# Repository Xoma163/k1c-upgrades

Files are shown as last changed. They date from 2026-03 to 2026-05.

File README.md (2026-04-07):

# k1c-upgrades

Klipper configs, mods, and upgrade notes for the Creality K1C.

## О репозитории

Этот репозиторий — моя личная база для хранения:

- конфигов принтера Creality K1C;
- заметок по модификациям;
- полезных ссылок;
- нюансов установки и использования.

Здесь нет подробных пошаговых инструкций — только краткие заметки и выжимка по тому, что оказалось полезным на практике.

## Что используется

- [SimpleAF + Eddy NG](https://pellcorp.github.io/creality-wiki/eddyng/) с **Default** креплением
- [Purcell nozzle wipe](https://pellcorp.github.io/creality-wiki/nozzle_wipe/#purcell-nozzle-wipe) с **V5K1C** креплением 

## Структура репозитория

- [`config/default`](config/default) — reference-база
- [`config/k1c #1`](config/k1c%20%231) — рабочие конфиги первого принтера
- [`config/k1c #2`](config/k1c%20%232) — рабочие конфиги второго принтера

Все мои ручные изменения в конфигах отмечены комментарием: `# custom andrewsha`

## Документация

- [Прошивка и конфиги](docs/firmware-and-configs.md)
- [Рабочая область и мёртвые зоны стола](docs/bed-area-and-dead-zones.md)
- [Модификации, детали и расходники](docs/mods-and-parts.md)
- [Полезные ссылки](docs/links.md)
- [TODO](docs/todo.md)

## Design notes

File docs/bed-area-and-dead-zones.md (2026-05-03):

# Рабочая область и мёртвые зоны стола

Для моего K1C есть несколько зон, которые надо исключать и в слайсере, и при настройке bed mesh.

## Исходные вводные

- заявленная область печати: `220x220`;
- фактический ход головы больше: примерно `226x229`;
- `0,0` — левый нижний угол стола;
- хоуминг происходит в правом нижнем углу.

## Какие зоны считаю unsafe

1. Левая мёртвая полоса (крепление Eddy):
   - если `x < 5`, печатать нельзя

2. Нижний левый угол (кастомные петли двери):
   - прямоугольник `0..8 x 0..5`

3. Верхняя полоса стола (датчик окончания филамента, провода, радиатор мотора экструдера):
   - из-за реального хода головы сверху запрещаю всё, что `y >= 210`
   - для рабочей области `220x220` это даёт прямоугольник: `0..220 x 210..220`

4. Зона щётки:
   - `165,225`
   - `165,205`
   - `85,205`
   - `85,225`
   - это даёт прямоугольник: `85..165 x 205..225`

## OrcaSlicer

### Print area
Лучше использовать не список исключённых областей, а готовый SVG: [orca-print-area.svg](orca-print-area.svg)

### Exclude area
В OrcaSlicer `multiple exclusion areas` нормально не поддерживаются, поэтому использую один связный полигон для `Excluded area`:

```text
0x0,8x0,8x5,5x5,5x210,85x210,85x205,165x205,165x210,220x210,220x220,0x220
```

Этот полигон исключает:

- полосу `x < 5`;
- нижний левый угол `0..8 x 0..5` из-за кастомных петель двери;
- верхнюю полосу `y >= 210`;
- зону щётки `85..165 x 205..225`.

## Klipper bed_mesh

Для `bed_mesh` оставляю 3 простых ограничения по рабочей области:

- `x > 5`;
- внизу слева дополнительно исключаю прямоугольник `0..8 x 0..5`;
- `y < 205`.

Через `faulty_region` это задаётся так:

```ini
# Left dead zone: avoid probing if X is below 5 mm
faulty_region_1_min: 0,0
faulty_region_1_max: 5,204.999
# Door hinges: avoid probing in the lower-left 0..8 x 0..5 rectangle
# Start slightly to the right of X=5 to avoid region overlap
faulty_region_2_min: 5.001,0
faulty_region_2_max: 8,5
# Top dead zone: avoid probing in the whole top strip above Y=205
faulty_region_3_min: 0,205
faulty_region_3_max: 220,220
```

### Где это лежит в конфиге сейчас

Текущая реализация в рабочих конфигах вынесена в override-слой:

- `faulty_region_*` живут в `custom.cfg` внутри секции `[bed_mesh]`;
- fixed purge / fixed smart park живут в `custom_macros.cfg` через `_SAF_LINE_PURGE` и `_SAF_SMART_PARK`;
- сами fixed координаты хранятся в `_CUSTOM_ANDREWSHA_SETTINGS` внутри `custom.cfg`.

Для обоих рабочих наборов сейчас используются такие fixed координаты purge/park:

- старт purge / park: `X=85`, `Y=212`;
- конец purge: `X=35`, `Y=212`;
- после purge есть дополнительный безопасный уход в `X35 Y200`.

## Тестовый G-code для проверки границы

Ниже тестовый G-code, который медленно проходит по боевой границе доступной области без экструзии:

```gcode
G90
G28
G1 Z10 F600
G1 X8 Y0 F1800
G1 X220 Y0 F1200
G1 X220 Y210 F1200
G1 X165 Y210 F1200
G1 X165 Y205 F1200
G1 X85 Y205 F1200
G1 X85 Y210 F1200
G1 X5 Y210 F1200
G1 X5 Y5 F1200
G1 X8 Y5 F1200
G1 X8 Y0 F1200
```

### Важно

- запускать этот тест лучше с рукой на **Emergency Stop**;
- безопаснее всего запускать его **построчно из консоли Klipper/Mainsail/Fluidd**, а не целым файлом;
- перед запуском убедитесь, что сопло поднято, стол пустой, а рядом нет клипс, инструментов и посторонних деталей.

## Тестовая STL-рамка по боевой границе

В репозитории лежит готовая модель: [`dead-zone-boundary-frame.stl`](dead-zone-boundary-frame.stl)

Что это такое:

- тонкая рамка по боевой границе доступной области;
- сама рамка построена не по точной боевой границе, а по контрольному контуру, вжатому внутрь примерно на `1 мм` с каждой стороны;
- высота модели `0.2 мм`;
- ширина линии рамки примерно `1 мм`.

Смысл модели — быстро проверить реальную печать по границе разрешённой зоны с учётом:

- слева в основном поле `x >= 6`;
- внизу слева контрольного выреза под петли двери `0..9 x 0..6`;
- `y < 209`;
- дополнительно расширенного контрольного выреза под щётку `83..167 x 203..226`.

Перед реальной печатью этой STL всё равно лучше сначала прогнать тестовый G-code выше, а саму первую печать запускать под наблюдением.

### Как печатать эту STL в OrcaSlicer

1. Временно включить ограничения стола и свериться, что модель встаёт правильно относительно мёртвых зон.
2. Разместить модель в позиции `X=112.50`, `Y=105.0`.
3. Проверить визуально, что рамка проходит там, где ожидается.
4. Временно убрать ограничения стола.
5. Отправить модель на печать.
6. Если печать прошла нормально, вернуть ограничения стола обратно.

Это нужно потому, что OrcaSlicer считает модель слишком близкой к области исключения и не даёт запустить печать, даже если эта тестовая рамка специально сделана для проверки самой границы.

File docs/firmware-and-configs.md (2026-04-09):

# Прошивка и конфиги

## Что используется

- [SimpleAF + Eddy NG](https://pellcorp.github.io/creality-wiki/eddyng/) с **Default** креплением;
- [Purcell nozzle wipe](https://pellcorp.github.io/creality-wiki/nozzle_wipe/#purcell-nozzle-wipe) с креплением **V5K1C**.

## Почему SimpleAF

Я сознательно ушёл от стоковой прошивки `Creality` и `Creality Helper Script` в пользу конфигурации, где можно полностью контролировать:

- хоуминг;
- bed mesh;
- старт/завершение печати;
- purge / park / wipe сценарии;
- fan logic и обслуживающие макросы.

## Важное ограничение

Если планируете переход на SimpleAF, нужен альтернативный способ картографии стола.

В этой конфигурации используется **BTT Eddy / Eddy NG**, потому что SimpleAF **не опирается на штатные тензодатчики K1C** как на основной механизм картографии.

## Где лежат конфиги

Все конфиги находятся в [`config`](../config).

Структура такая:

- [`config/default`](../config/default) — reference-база, ближайшая к апстриму SimpleAF;
- [`config/k1c #1`](../config/k1c%20%231) — рабочий набор первого принтера;
- [`config/k1c #2`](../config/k1c%20%232) — рабочий набор второго принтера.

Важно: `k1c #1` и `k1c #2` — это **самодостаточные рабочие наборы**, а не наследование от `default/` на runtime.

## Ключевые файлы

### Базовые

- `printer.cfg` — главный входной файл Klipper, include-порядок и hardware-секции;
- `homing.cfg` — sensorless XY, `homing_override`, проверки перед Z homing;
- `eddyng.cfg` — probe, mesh, screws tilt, axis twist;
- `eddyng_macro.cfg` — обёртки вокруг `BED_MESH_CALIBRATE` и `PROBE_EDDY_NG_TAP`;
- `start_end.cfg` — `START_PRINT`, `END_PRINT`, pause/resume/cancel/runout;
- `fan_control.cfg` — логика part/chamber/auxiliary/hotend fan;
- `useful_macros.cfg` — сервисные макросы, включая загрузку/выгрузку филамента.

### Кастомные

- `custom.cfg` — значения и overrides, которые должны идти поверх дефолтных секций;
- `custom_macros.cfg` — поведенческие overrides через `_SAF_*` hooks;
- `advanced_nozzle_cleaner.cfg` — отдельный модуль Purcell nozzle wipe.

### Moonraker / UI

- `moonraker.conf` — Moonraker и include'ы;
- `webcam.conf` — локальный URL камеры;
- `grumpyscreen.ini` — настройки экрана.

## Текущая стратегия кастомизации

Текущая цель репозитория — держать рабочие конфиги как можно ближе к `default/`, а ручные правки концентрировать в явных override-слоях.

Подробно схема описана в отдельном файле: [Слои кастомизации и override-стратегия](config-overrides.md).

Короткая версия:

- `printer.cfg` остаётся максимально близким к дефолту;
- `custom.cfg` хранит численные и variable-based overrides;
- `custom_macros.cfg` хранит поведенческие overrides через `_SAF_*` hooks;
- большие отдельные модули остаются отдельными include-файлами.

## Как помечаются ручные правки

Ручные изменения стараюсь отмечать комментарием `# custom andrewsha`.

Но с текущей архитектурой сама по себе локация правки уже тоже несёт смысл:

- если изменение лежит в `custom.cfg`, это override значения;
- если лежит в `custom_macros.cfg`, это override поведения;
- если лежит в `advanced_nozzle_cleaner.cfg`, это отдельный модуль nozzle wipe.

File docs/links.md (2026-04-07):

# Полезные ссылки

## Основные источники

- [SimpleAF docs](https://pellcorp.github.io/creality-wiki/)
- [SimpleAF + Eddy NG](https://pellcorp.github.io/creality-wiki/eddyng/)
- [Purcell nozzle wipe](https://pellcorp.github.io/creality-wiki/nozzle_wipe/#purcell-nozzle-wipe)
- [Основная таблица с апгрейдами](https://docs.google.com/spreadsheets/d/1lo7YX4nkfYGhhncVtIryOvbDM4tTaRjzZT0Y3F5O7gI)

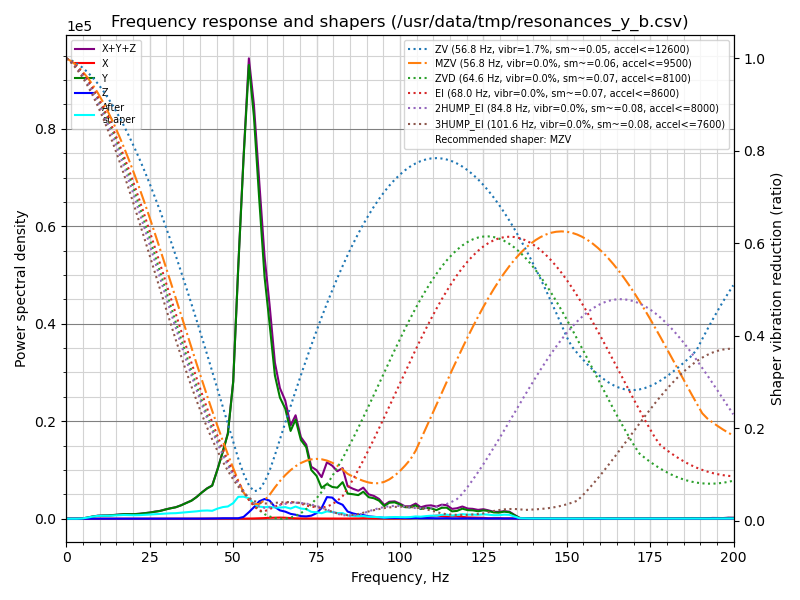
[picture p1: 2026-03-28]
config/k1c #1/images/resonances_y.png

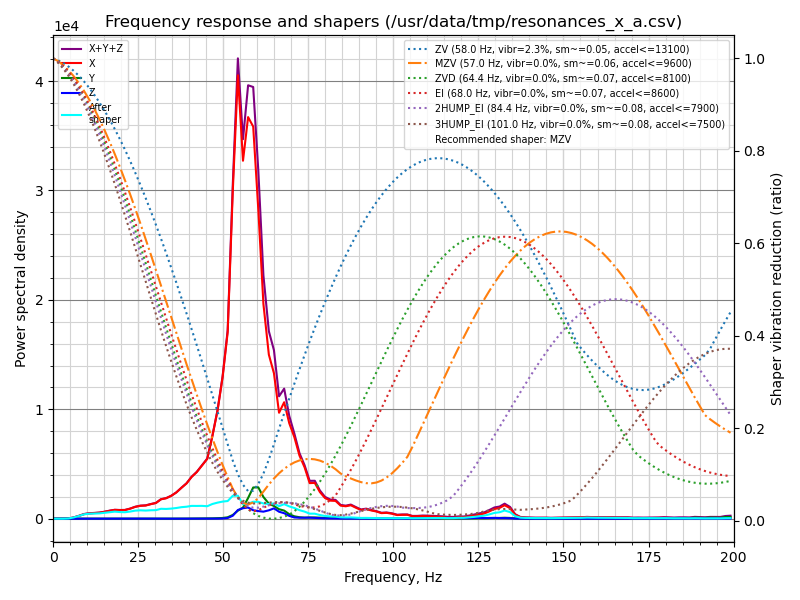
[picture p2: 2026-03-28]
config/k1c #2/images/resonances_x.png

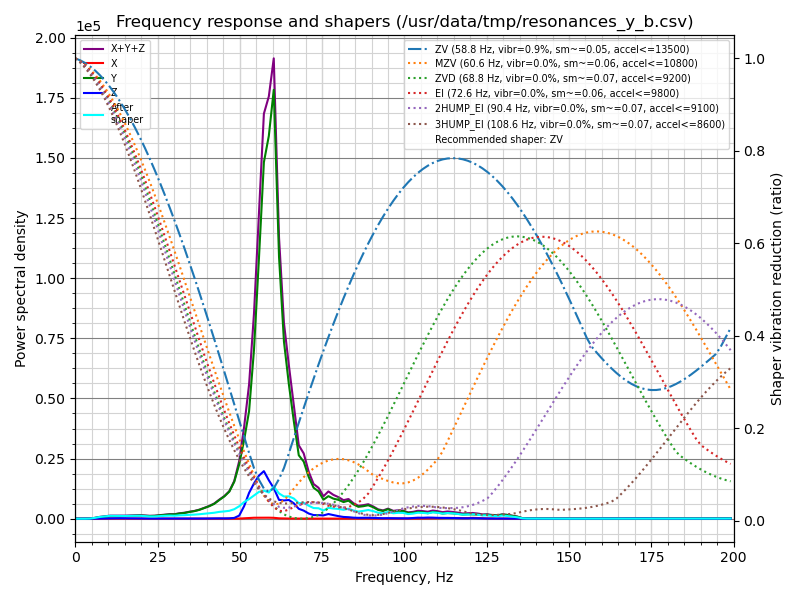
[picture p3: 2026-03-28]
config/k1c #2/images/resonances_y.png

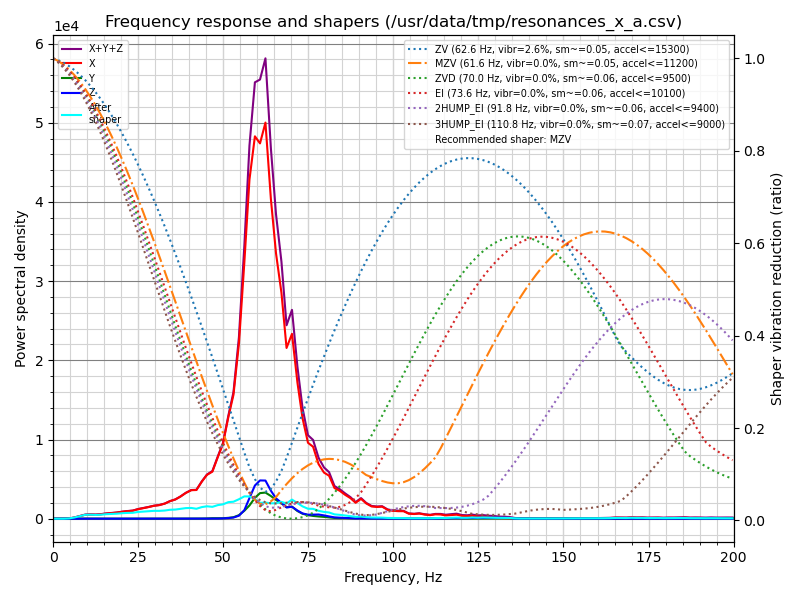
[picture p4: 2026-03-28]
config/k1c #1/images/resonances_x.png

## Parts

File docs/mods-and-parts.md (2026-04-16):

# Модификации, детали и расходники

## Печатные модификации

- [Райзер](https://www.printables.com/model/951012-creality-k1-k1c-k1se-lid-riser-v3-frame-extension)
- [Держатель щётки](https://www.printables.com/model/1023575-prowiper-for-creality-k1-series)
    - V5K1C крепление: `V5 K1C BRUSH MOUNT FOR A1 BRUSHES.stl`
- [Петли для дверцы](https://www.printables.com/model/916563-creality-k1-k1c-door-hinges-geared-print-in-place)
- [Фильтр HEPA для выдувного кулера](https://www.printables.com/model/1618123-hepa-filter-case-for-creality-k1c)
- [Полочка под принтер](https://www.printables.com/model/1114893-k1c-empty-tray)
- [Крепление BTT Eddy](https://www.printables.com/model/1637215-remix-of-btteddy-creality-k1-k1c-k1-max-mount-to-w)
- [Кабельная цепь](https://www.printables.com/model/1684322-cable-chain-for-k1k1c-with-ptfe-guide-increased-fo)

- [Держатель трубки филамента для сушилки](https://www.printables.com/model/1022857-creality-space-pi-pfte-holder)

## Покупные модификации

- Eddy
    - [Картограф BIGTREETECH Eddy Duo Eddy](https://aliexpress.ru/item/1005006917842625.html)
    - [Коннекторы JST PH 2.0мм 4pin (для подключения Eddy)](https://www.ozon.ru/product/jst-ph-2-0mm-4pin-kabel-s-razemom-30sm-razem-na-platu-jst-ph-4pin-5sht-1854551013/)
    - [Коннекторы JST PH 1.5мм 4pin (для подключения Eddy)](https://www.ozon.ru/product/jst-zh-1-5-mm-4pin-kabel-s-razemom-30sm-razem-na-platu-jst-zh-4pin-5sht-2624681705/)
    - [Кабель силиконовый 4pin 0.12мм^2 (для подключения Eddy)](https://www.ozon.ru/product/microtec-silovoy-kabel-4-x-0-12-mm-3-m-1867569044/)

- Моторы и радиаторы
    - [Радиаторы моторов XYZ](https://aliexpress.ru/item/32624104352.html)
    - [Радиатор мотора экструдера](https://aliexpress.ru/item/1005008673674752.html)

- Остальное
    - [Бипер](https://aliexpress.ru/item/1005006744589368.html)
    - [Экструдер FYSETC Phaetus DXC V1.1](https://aliexpress.ru/item/1005009096708545.html)
    - [Прозрачная PTFE трубка 2.5 x 4 мм](https://aliexpress.ru/item/1005007856169379.html)
    - [Кабель канал 25 x 16мм](https://www.ozon.ru/product/kabel-kanal-ruvinil-25h16-mm-chernyy-1-metr-1-sht-502978136/)
    - [Винты M3](https://www.ozon.ru/product/vint-m-3h16-s-potaynoy-golovkoy-din-965-100-sht-874104112/)
    - [Латунные втулки M3](https://www.ozon.ru/product/120-sht-m3x5-7-od4-6-rezba-s-nakatkoy-iz-latuni-s-rezboy-termostoykaya-termostoykaya-vstavka-1719174667/)

## Расходники

- [Оригинальные печатные пластины](https://aliexpress.ru/item/1005006912703598.html)
- [Неоригинальные печатные пластины](https://aliexpress.ru/item/1005006604536598.html)
- [Носки](https://aliexpress.ru/item/1005007193585076.html)
- [Щётки](https://aliexpress.ru/item/1005007695468858.html)
- [Сопла Trianglelab unicorn](https://aliexpress.ru/item/1005006727982293.html)
- [Сопла Creality unicorn](https://aliexpress.ru/item/1005006861530583.html)
- [Железные шестерни экструдера](https://aliexpress.ru/item/1005007150902009.html)
- [Стоковый хотенд в сборе](https://aliexpress.ru/item/1005008125402700.html)
- [Клей для 3д печати](https://www.ozon.ru/product/kley-dlya-3d-fdm-pechati-250-ml-universalnyy-dlya-3d-printera-kley-dlya-vseh-vidov-plastika-788061034)

## Полезные штучки

- [Сушилка филамента Creality Space Pi Fillament Dryer Plus](https://aliexpress.ru/item/1005006458650443.html)

## Откуда брать идеи для модов?

- [Основная таблица с апгрейдами](https://docs.google.com/spreadsheets/d/1lo7YX4nkfYGhhncVtIryOvbDM4tTaRjzZT0Y3F5O7gI)

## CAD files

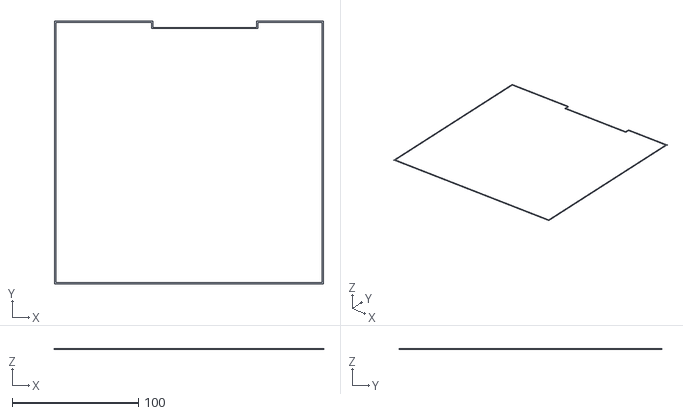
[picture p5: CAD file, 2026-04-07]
docs/dead-zone-boundary-frame.stl
213.0 x 208.0 x 0.2

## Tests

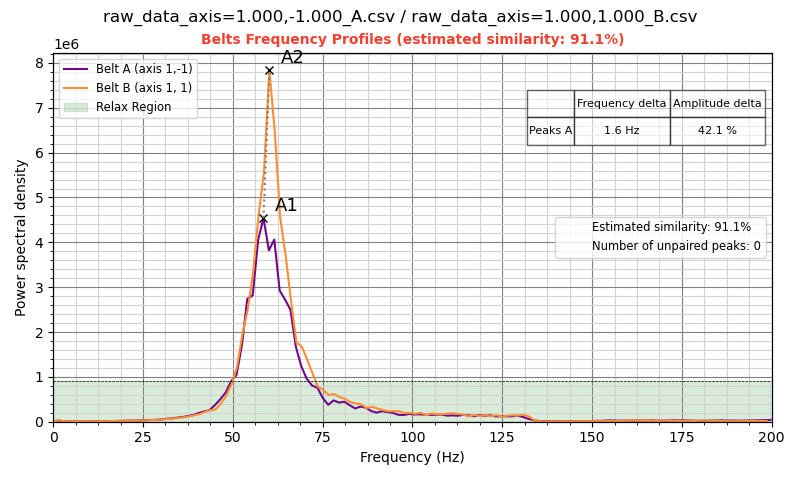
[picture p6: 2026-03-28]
config/k1c #2/images/belts_calibration.png

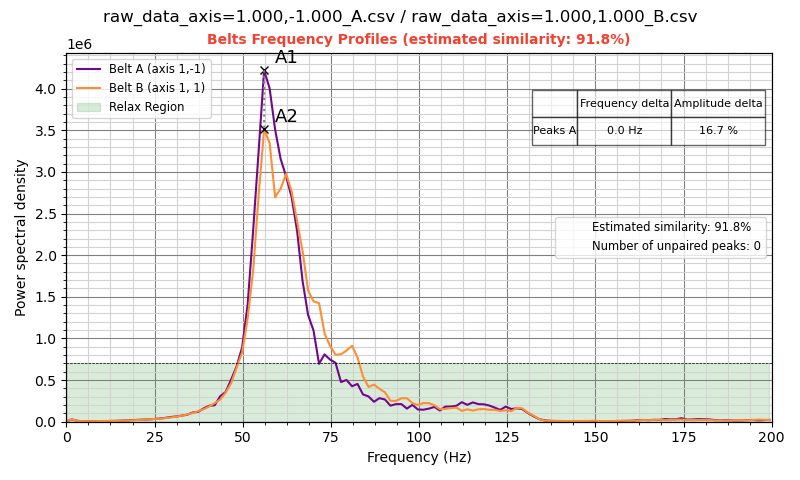
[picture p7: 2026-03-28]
config/k1c #1/images/belts_calibration.png

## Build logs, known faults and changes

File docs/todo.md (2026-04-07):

# TODO

- Заменить `variable_purge_start_y` и `variable_purge_end_y` с `212` на `215`, когда заменю пластины

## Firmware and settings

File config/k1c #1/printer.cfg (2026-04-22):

# Modified by Simple AF 2026-03-28_13-22-50

[include homing.cfg]

[include internal_macros.cfg]

[include useful_macros.cfg]

[include belts_calibration.cfg]

[include start_end.cfg]

[include Line_Purge.cfg]

[include Smart_Park.cfg]

[include fan_control.cfg]

[include client.cfg]

[include quickstart.cfg]

[include eddyng.cfg]

[include eddyng_macro.cfg]

[mcu]
serial: /dev/ttyS7
baud: 230400
restart_method: command

[mcu nozzle_mcu]
serial: /dev/ttyS1
baud: 230400
restart_method: command

[verify_heater extruder]
[verify_heater heater_bed]
check_gain_time: 120
heating_gain: 1.0
hysteresis: 10

[gcode_arcs]
resolution: 1.0

[stepper_x]
step_pin: PC2
dir_pin: !PB9
enable_pin: !PC3
microsteps: 32
rotation_distance: 40
endstop_pin: tmc2209_stepper_x:virtual_endstop
position_endstop: 229
position_min: -5
position_max: 229
homing_speed: 30
homing_retract_dist:0

[tmc2209 stepper_x]
uart_pin:PA9
interpolate: True
run_current:1.5
sense_resistor: 0.100
stealthchop_threshold: 0
uart_address:3
diag_pin: ^PB12
# driver_IHOLDDELAY: 8
# driver_TPOWERDOWN: 20
# driver_TBL: 1
# driver_TOFF: 1
# driver_HEND: 0
# driver_HSTRT: 7
driver_SGTHRS: 75
# hold_current:1.0

[stepper_y]
step_pin: PB8
dir_pin: !PB7
enable_pin: !PC3
microsteps: 32
rotation_distance: 40
endstop_pin: tmc2209_stepper_y:virtual_endstop
position_endstop: -0.5
position_min: -0.5
position_max: 226
homing_speed: 30
homing_retract_dist:0

[tmc2209 stepper_y]
uart_pin:PA10
interpolate: True
run_current:1.5
sense_resistor: 0.100
stealthchop_threshold: 0
uart_address:3
diag_pin: ^PB13
# driver_IHOLDDELAY: 8
# driver_TPOWERDOWN: 20
# driver_TBL: 1
# driver_TOFF: 1
# driver_HEND: 0
# driver_HSTRT: 7
driver_SGTHRS: 75
# hold_current:1.0

[stepper_z]
step_pin: PB6
dir_pin: !PB5
enable_pin: !PC3
microsteps: 16
rotation_distance:8
gear_ratio: 64:20
endstop_pin: probe:z_virtual_endstop
position_max: 252
position_min: -5
# position_endstop: 0

[tmc2209 stepper_z]
uart_pin: PA11
uart_address: 3
run_current: 0.8
diag_pin: ^PB14
stealthchop_threshold: 0
sense_resistor: 0.100
# driver_IHOLDDELAY: 8
# driver_TPOWERDOWN: 20
# driver_TBL: 1
# driver_TOFF: 1
# driver_HEND: 2
# driver_HSTRT: 2
driver_SGTHRS: 0

[extruder]
max_extrude_only_distance: 1000.0
max_extrude_cross_section: 80
step_pin: nozzle_mcu:PB1
dir_pin: nozzle_mcu:PB0
enable_pin: !nozzle_mcu:PB2
microsteps: 16
rotation_distance: 6.9
nozzle_diameter: 0.400
filament_diameter: 1.750
heater_pin: nozzle_mcu:PB7
sensor_type: EPCOS 100K B57560G104F
sensor_pin: nozzle_mcu:PA0
pressure_advance: 0.04
pressure_advance_smooth_time: 0.040
control: pid
pid_Kp: 25.013
pid_Ki: 2.566
pid_Kd: 60.966
min_temp: 0
max_temp: 320

[tmc2209 extruder]
uart_pin: nozzle_mcu:PB11
tx_pin: nozzle_mcu:PB10

uart_address: 3
run_current: 0.55
sense_resistor: 0.150
stealthchop_threshold: 0
# driver_IHOLDDELAY: 8
# driver_TPOWERDOWN: 20
# driver_TBL: 2
# driver_TOFF: 3
# driver_HEND: 0
# driver_HSTRT: 5

[heater_bed]
heater_pin: PB10
sensor_type: EPCOS 100K B57560G104F
sensor_pin: PC4
control: watermark
min_temp: 0
max_temp: 115

[filament_switch_sensor filament_sensor]
pause_on_runout: false
switch_pin: !PC15
runout_gcode: _ON_FILAMENT_RUNOUT

[output_pin LED]
pin:PB0
pwm: True
cycle_time: 0.010
value: 1

[adxl345]
cs_pin: nozzle_mcu:PA4
spi_speed: 5000000
axes_map: x,-z,y
spi_software_sclk_pin: nozzle_mcu:PA5
spi_software_mosi_pin: nozzle_mcu:PA7
spi_software_miso_pin: nozzle_mcu:PA6

[resonance_tester]
accel_chip: adxl345
accel_per_hz: 75
# min_freq: 30
# max_freq: 100
probe_points:
   110,110,10

[printer]
kinematics: corexy
max_velocity: 600
max_accel: 20000
max_z_velocity: 10
square_corner_velocity: 5.0
# square_corner_max_velocity: 200.0
# max_accel_to_decel: 20000
max_z_accel: 300

[probe_eddy_ng btt_eddy]

[exclude_object]

# custom andrewsha https://pellcorp.github.io/creality-wiki/nozzle_wipe/#purcell-nozzle-wipe
[include advanced_nozzle_cleaner.cfg]

# custom andrewsha (переопределения переменных)
[include custom.cfg]

# custom andrewsha (переопределения макросов)
[include custom_macros.cfg]

#*# <---------------------- SAVE_CONFIG ---------------------->
#*# DO NOT EDIT THIS BLOCK OR BELOW. The contents are auto-generated.
#*#
#*# [bed_mesh default]
#*# version = 1
#*# points =
#*# 	-0.007990, 0.001714, -0.023951, -0.043306, -0.058533, -0.059196, -0.042648, -0.028529, -0.027213, -0.021002, -0.018720, -0.037382, -0.051236, -0.049915, -0.047927, -0.045949, -0.035748, -0.045949, -0.044957, -0.051236
#*# 	0.015546, 0.020992, -0.008639, -0.019372, -0.038039, -0.036724, -0.014819, -0.001200, 0.000426, 0.004296, 0.002683, -0.011891, -0.033437, -0.033437, -0.033437, -0.019382, -0.027538, -0.034751, -0.046608, -0.059196
#*# 	0.001072, 0.011377, -0.001838, -0.007342, -0.025577, -0.021002, -0.003454, 0.008807, 0.015870, 0.017798, 0.011059, -0.008639, -0.024923, -0.028193, -0.024269, -0.015471, -0.025577, -0.034751, -0.050575, -0.066850
#*# 	-0.016440, 0.001072, 0.002989, 0.012021, -0.017743, -0.015138, -0.000870, 0.009452, 0.011377, 0.008807, 0.009760, -0.004107, -0.029503, -0.033459, -0.039352, -0.034751, -0.041989, -0.047927, -0.058533, -0.075877
#*# 	-0.033437, -0.003454, 0.002038, 0.009452, -0.005722, -0.005399, 0.007516, 0.010097, 0.005588, -0.002487, -0.009290, -0.011571, -0.036724, -0.038054, -0.050575, -0.042663, -0.056536, -0.060859, -0.069183, -0.075537
#*# 	-0.042003, -0.013838, -0.001838, 0.008162, -0.004103, -0.007342, -0.004102, -0.000870, -0.002499, -0.022308, -0.030159, -0.039684, -0.049255, -0.052893, -0.056536, -0.055212, -0.050590, -0.065519, -0.069183, -0.080569
#*# 	-0.055874, -0.017743, -0.000870, 0.018104, 0.008794, -0.003454, 0.002674, -0.007342, -0.017743, -0.028848, -0.032782, -0.039027, -0.046608, -0.045949, -0.047267, -0.047927, -0.054550, -0.059859, -0.066523, -0.076545
#*# 	-0.060522, -0.024923, -0.014814, 0.001072, 0.001718, -0.005399, -0.010585, -0.006381, -0.024923, -0.030814, -0.033437, -0.034751, -0.031811, -0.034751, -0.036724, -0.034751, -0.041330, -0.046608, -0.050575, -0.066523
#*# 	-0.068523, -0.036395, -0.024269, -0.000870, 0.007198, 0.000426, -0.007990, -0.013187, -0.010923, -0.011892, -0.009623, -0.016440, -0.014814, -0.016440, -0.019697, -0.024596, -0.019703, -0.027876, -0.024269, -0.049915
#*# 	-0.094037, -0.058533, -0.019697, -0.013511, -0.013200, -0.002495, -0.019372, -0.023942, -0.033437, -0.021993, -0.024923, -0.022962, -0.024269, -0.023616, -0.024269, -0.024269, -0.023299, -0.038039, -0.041989, -0.059196
#*# 	-0.107591, -0.058197, -0.034751, -0.014162, -0.010263, -0.015789, -0.025577, -0.034751, -0.042648, -0.044629, -0.036395, -0.029843, -0.040673, -0.041330, -0.044629, -0.043306, -0.056536, -0.053563, -0.058206, -0.081909
#*# 	-0.052904, -0.024923, -0.007342, 0.003649, -0.004103, -0.009940, -0.021002, -0.033437, -0.048921, -0.051236, -0.043306, -0.044957, -0.049255, -0.049915, -0.050575, -0.052893, -0.061185, -0.061533, -0.077214, -0.099444
#*# 	-0.046608, 0.003649, 0.017155, 0.020357, 0.005906, -0.008639, -0.011241, -0.032782, -0.047267, -0.044307, -0.041346, -0.049915, -0.053889, -0.057534, -0.063851, -0.070189, -0.072878, -0.082929, -0.094037, -0.109971
#*# 	-0.032800, -0.005399, 0.003649, 0.003649, -0.007342, -0.021655, -0.025577, -0.034751, -0.047927, -0.036724, -0.045948, -0.047267, -0.052893, -0.055212, -0.059196, -0.064515, -0.075209, -0.088299, -0.096055, -0.119192
#*# 	-0.027876, 0.015546, 0.008162, 0.001072, -0.012542, -0.032782, -0.031811, -0.041330, -0.042006, -0.047267, -0.042648, -0.047267, -0.038696, -0.059196, -0.058549, -0.066194, -0.089315, -0.095383, -0.102164, -0.117127
#*# 	-0.041000, -0.009290, -0.013187, -0.019372, -0.034751, -0.051236, -0.053889, -0.042003, -0.042003, -0.047267, -0.041989, -0.039697, -0.051236, -0.048933, -0.063187, -0.069183, -0.080569, -0.094037, -0.101489, -0.114751
#*# 	-0.051236, -0.015789, -0.019697, -0.025577, -0.029503, -0.056536, -0.055212, -0.053889, -0.051896, -0.048261, -0.039697, -0.038696, -0.062187, -0.051896, -0.072529, -0.072536, -0.092346, -0.102838, -0.110999, -0.122948
#*# 	-0.064515, -0.042648, -0.041330, -0.036739, -0.043650, -0.055212, -0.052893, -0.051236, -0.049255, -0.047267, -0.044957, -0.051896, -0.053567, -0.063851, -0.063187, -0.056885, -0.072527, -0.085272, -0.094710, -0.116448
#*# 	-0.053889, -0.038039, -0.043964, -0.044957, -0.047927, -0.047927, -0.042648, -0.041330, -0.041989, -0.042648, -0.042648, -0.055212, -0.065180, -0.063851, -0.058533, -0.057870, -0.067854, -0.075877, -0.081909, -0.091015
#*# 	-0.085272, -0.071862, -0.073860, -0.068868, -0.079901, -0.065531, -0.067188, -0.064515, -0.064515, -0.066523, -0.066523, -0.070196, -0.086612, -0.082578, -0.070191, -0.065519, -0.072529, -0.077214, -0.081239, -0.094725
#*# x_count = 20
#*# y_count = 20
#*# mesh_x_pps = 2
#*# mesh_y_pps = 2
#*# algo = bicubic
#*# tension = 0.2
#*# min_x = 10.0
#*# max_x = 204.94
#*# min_y = 10.0
#*# max_y = 209.88000000000005
#*#
#*# [bed_mesh default_cold_20x20]
#*# version = 1
#*# points =
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

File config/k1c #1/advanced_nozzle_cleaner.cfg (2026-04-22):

# https://pellcorp.github.io/creality-wiki/nozzle_wipe/#purcell-nozzle-wipe

# CHANGE THE BRUSH MOUNT VERSION BELOW. THE REST WILL AUTO DETECT WHEN RUNNING THE MACRO
# SET PRINTER VERSION TO CUSTOM TO OVERRIDE AUTOCONFIG. YOU MUST MANUALLY SET ALL VARIABLES USING CUSTOM.
# START_Z SETS THE DISTANCE BETWEEN THE NOZZLE AND THE -BED- WHILE WIPING. MEASURE AND VERIFY A SAFE HEIGHT.
# RUN THE MACRO WITH AN EMPTY BUILD PLATE BEFORE INSTALLING THE BRUSH MOUNT TO VERIFY SAFE SETTINGS.
# USE THE PRINTABLE TOOLS AND MEASUREMENT MACRO IF YOU NEED TO DIAL IN CUSTOM SETTINGS TO SUIT YOUR SETUP


# COMMENT OUT THE FOLLOWING 3 LINES IF YOU ARE GETTING A VIRTUAL PINS ERROR
# COMMENT OUT THE RELATED 3 LINES IN THE GCODE SECTION TOO
[output_pin ADVANCED_NOZZLE_WIPER]
 pin: virtual_pin:ADVANCED_NOZZLE_WIPER_pin
 value: 1

[gcode_macro _SAF_NOZZLE_WIPE]
gcode:
    # make the nozzle wipe be a good citizen and restore the target temp afterwards
    {% set target_nozzle_temp = printer[printer.toolhead.extruder].target %}

    WIPE_NOZZLE

    # then restore the previous nozzle temp
    M109 S{target_nozzle_temp}

[gcode_macro WIPE_NOZZLE]
description: Advanced Nozzle Wiper Version 4.9 (17-02-2025)

# ___________________________________________________________________________________

# MAKE SURE THE BRUSH MOUNT MATCHES YOUR SETUP. THE REST SHOULD AUTO ADJUST. USE CUSTOM PRINTER IF YOU WANT TO CHANGE Z
# ___________________________________________________________________________________

variable_brush_mount        : "V5K1C"      # <------- CHANGE TO A1, V5K1C, OGK1C, A1MINI, V4MINI, LPF, LPF2, LIBRA, LIBRA2, MOLDED, NONE
variable_printer_version    : "K1C"       # <------- AUTO DETECTS K1, K1C, K1SE, K1MAX. SET TO CUSTOM TO CHANGE VARIABLES MANUALLY
variable_start_z            : 8.5         # <------- AUTOMATICALLY CHANGES BASED ON BRUSH IF NOT USING CUSTOM
variable_wipe_pattern       : "STRAIGHT"  # <------- STRAIGHT / ZIGZAG / DISABLED. ONLY STRAIGHT IS SUPPORTED FOR LPF MOUNTS


# START_Z WILL DEFAULT TO 4 FOR LPF2, 5 FOR LPF, 0.05 FOR NONE AND 8.5 FOR OLDER MOUNTS
# "NONE" WILL SCRAPE THE NOZZLE ON THE BUILD PLATE LIKE THE FACTORY K1 MAX (WORST OPTION)
# THE ZIGZAG WIPE PATTERN WILL AUTOMATICALLY SWITCH TO STRAIGHT IF THERE ISN'T ENOUGH TRAVEL AREA AVAILABLE

# ___________________________________________________________________________________

# OPTIONS 

variable_speed              : 5000      # THIS CHANGES HOW FAST IT WIPES. I RECOMMEND 1000-5000.
variable_wipe_qty           : 5         # AMOUNT OF WIPE SEQUENCES. 1 FOR PURE SPEED, MORE RECOMMENDED TO AVOID LEAKS
variable_safe_temp          : 10        # NOZZLE WILL HEAT TO THE PRINT TEMP MINUS THE SAFE TEMP TO AVOID LEAKS
variable_preheat            : "OFF"     # KEEPS THE NOZZLE WARM TO HELP PREHEAT THE CHAMBER BEFORE PRINTING
variable_hot_wipe           : "ON"      # WAIT UNTIL THE NOZZLE IS HEATED BEFORE WIPING. REQUIRED FOR EXTRUDE / RETRACT
variable_ensure_cooling     : "OFF"     # ADDS EXTRA WIPES TO GIVE THE NOZZLE TIME TO COOL. HELPS AVOID LEAKS
variable_extrude_amount     : "OFF"     # VALUE / OFF. EXTRUDE BEFORE WIPING. MUST INCREASE FIRST LAYER TEMP TO USE
variable_retract_amount     : "OFF"     # VALUE / OFF. RETRACT AFTER EXTRUDING BEFORE WIPING TO AVOID LEAKS
variable_console_output     : "ON"      # ON, OFF. ENABLES OR DISABLES EXTRA INFO IN CONSOLE FOR DIAGNOSTIC PURPOSES
variable_bot_clearance      : 20        # HOW MUCH CLEARANCE YOU NEED UNDER THE BED FOR MODS OR STORAGE.
variable_drop_distance      : 30        # LOWERS THE BED BY THIS MUCH BEFORE MOVING TO AVOID COLLISIONS.
variable_bed_fans_installed : "FALSE"   # SET TO TRUE IF YOU HAVE BED FANS DEFINED AS BED_FANS IN PRINTER.CFG
variable_preheat_bed_temp   : 110       # AFTER WIPING, PREHEATS THE BED TO THIS TEMP IF PREHEAT IS ON
variable_preheat_nozzle_temp: 80        # AFTER WIPING, PREHEATS THE NOZZLE TO THIS TEMP IF PREHEAT IS ON
variable_fan_speed          : 175       # 0-255. AFTER WIPING, SETS FANS TO THIS SPEED IF PREHEAT IS ON
variable_scrape_position    : "FRONT"   # FRONT / SIDE / REAR - SCRAPES IN THIS POSITION IF BRUSH MOUNT IS NONE
variable_scrape_z_height    : 0.05      # ADJUSTS THE Z POSITION WHEN WIPING WITHOUT A BRUSH
variable_first_layer_temp   : 220       # HEATS NOZZLE TO THIS TEMP BEFORE WIPING
variable_placed             : "NO"      # FORCES START Z TO 2.5 TO USE A BRUSH PLACED WITHOUT A MOUNT
variable_spacer_height      : 0         # MODIFIES THE Z OFFSET TO ACCOUNT FOR A SPACER FOR MODIFIED BEDS

# ___________________________________________________________________________________

#VARIABLES BELOW WILL CHANGE AUTOMATICALLY IF PRINTER VERSION AND  ARE NOT SET TO CUSTOM

variable_start_x            : 121       # CHANGES AUTOMATICALLY DEPENDING ON BRUSH AND PRINTER TYPE
variable_start_y            : 222.5     # CHANGES AUTOMATICALLY DEPENDING ON BRUSH AND PRINTER TYPE
variable_brush_length       : 50        # CHANGES AUTOMATICALLY DEPENDING ON BRUSH TYPE. ADD 3 FOR CUSTOM LENGTHS
variable_wipe_distance      : 50        # CHANGES AUTOMATICALLY BASED ON BRUSH LENGTH
variable_top_clearance      : 20        # THE BED WILL LOWER BY THE DROP DISTANCE IF IT IS ABOVE THIS VALUE
variable_limit_z            : 250       # CHANGES AUTOMATICALLY TO REFLECT YOUR -FACTORY- BUILD VOLUME
variable_limit_x            : 220       # CHANGES AUTOMATICALLY TO REFLECT YOUR -FACTORY- BUILD VOLUME
variable_limit_y            : 220       # CHANGES AUTOMATICALLY TO REFLECT YOUR -FACTORY- BUILD VOLUME
variable_target_temp        : 140       # COOLS TO THIS TEMP WHILE WIPING TO AVOID LEAKS


variable_config_version: "V4.9 (17-02-2025)"

# ___________________________________________________________________________________

gcode:
  # TOGGLE BUTTON IN FLUIDD AND SAFETY FEATURE TO PROTECT AGAINST DAMAGE FROM MISCONFIGURATION.
  # COMMENT THIS OUT IF YOU ARE GETTING A VIRTUAL PINS ERROR
  {% if printer['output_pin ADVANCED_NOZZLE_WIPER'].value == 0 %}
  {% set wipe_pattern = "DISABLED" %}
  {% endif %}

  {% if wipe_pattern not in ["OFF", "DISABLED"] %}
  # SAFETY CHECK
    {% if brush_mount == "CHANGE ME" %}
    RESPOND PREFIX="You need to set the [brush_mount] type in  [advanced_nozzle_wiper.cfg]"
    {% set wipe_pattern = "DISABLED" %}
    {% endif %}


        #{% if 'SPEED' in params %}
        #{% set speed = params.SPEED|default(speed)|int %}
        #{% endif %}
    {% if 'BED_TEMP' in params|upper and (params.BED_TEMP|float) %}
  {% set preheat_bed_temp = params.BED_TEMP|float %}
  {% endif %}

  {% if 'EXTRUDER_TEMP' in params|upper and (params.EXTRUDER_TEMP|float) %}
    {% set first_layer_temp = params.EXTRUDER_TEMP|float %}
   {% endif %}

  {% if 'EXTRUDER_TEMP' in params|upper and (params.EXTRUDER_TEMP|float) %}
    {% set first_layer_temp = params.EXTRUDER_TEMP|float %}
   {% endif %}

  {% if printer_version != "CUSTOM" and printer.configfile.settings.stepper_x.position_max > 250 %}
    {% set printer_version = "K1MAX" %}
    {% set limit_x = 300 %}
    {% set limit_y = 300 %}
    {% set limit_z = 300 %}
    {% elif variable_printer_version != "CUSTOM" and printer.configfile.settings.stepper_x.position_max < 250 %}
    {% set limit_x = 220 %}
    {% set limit_y = 220 %}
    {% set limit_z = 250 %}
    {% endif %}

    # INITIALIZATION
    #{% set start_x = (limit_x / 2) - (brush_length / 2) %} # -1.5
    {% if brush_mount not in ["LPF", "LPF1", "LPF2", "CUSTOM"] %}
              {% set start_y = (printer.configfile.settings.stepper_y.position_max - 2.6) %}
    {% endif %}

    # START HEATING NOZZLE
    M104 S{target_temp}

    # WIPING DIRECTLY ON PLATE
    {% if brush_mount == "NONE" and scrape_position in ["FRONT", "SIDE"] %}
        {% set wipe_pattern = "STRAIGHT" %}
    {% endif %}

    # A1 MINI / MOLDED
    {% if brush_mount in ["A1MINI", "MOLDED"] and printer_version != "CUSTOM" %}
        {% set brush_length = 61 %}
        {% set start_z = 8.5 %}
        {% elif brush_mount in ["A1", "K1", "LPF"] and printer_version != "CUSTOM" %}
        {% set brush_length = 38 %}
    {% endif %}

    # V4MINI
    {% if brush_mount == "V4MINI" and printer_version != "CUSTOM" %}
        {% set start_z = 6.5 %}
        {% set brush_length = 31 %}
    {% endif %}

    # STOCK K1C
    {% if brush_mount == "OGK1C" and printer_version != "CUSTOM" %}
        {% set start_z = 2.25 %}
        {% set brush_length = 51 %}
    {% endif %}
    # ORIGINAL K1C
    {% if brush_mount == "V5K1C" and printer_version != "CUSTOM" %}
        {% set start_z = 4.5 %}
        {% set brush_length = 38 %}
    {% endif %}

    # LPF / LPF1
     {% if brush_mount in ["LPF", "LPF1"] and printer_version != "CUSTOM" %}
        {% set start_y = (printer.configfile.settings.stepper_y.position_max - 2.6) %}
        {% set start_z = 4 %}
        {% set brush_length = 38 %}
       {% set wipe_pattern = "STRAIGHT" %}
     {% endif %}
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

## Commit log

2026-03-28 upd k1c1 config
    [advanced_nozzle_cleaner.cfg, custom.cfg, eddyng.cfg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]
2026-03-28 upd configs
    [advanced_nozzle_cleaner.cfg, custom.cfg, eddyng.cfg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]
2026-04-03 upd tap_adjust_z
    [eddyng.cfg, printer.cfg]
2026-04-06 set default
    [advanced_nozzle_cleaner.cfg]
2026-04-06 nozzle wiper
    [advanced_nozzle_cleaner.cfg]
2026-04-06 config update
    [advanced_nozzle_cleaner.cfg, custom.cfg, eddyng.cfg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]
2026-04-07 update dead zone safety bounds
    [Smart_Park.cfg, eddyng.cfg, start_end.cfg]
2026-04-07 update dead zone limits
    [eddyng.cfg, start_end.cfg]
2026-04-07 add dead zone test frame
    [dead-zone-boundary-frame.stl, eddyng.cfg]
2026-04-07 update wipe mount and fixed purge path
    [Line_Purge.cfg, Smart_Park.cfg, advanced_nozzle_cleaner.cfg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]
2026-04-07 identical configurations on two printers
    [printer.cfg]
2026-04-07 split README into focused docs
    Reduce the top-level README to a short entry point and move firmware, bed area, parts, links, and todo notes into dedicated documentation pages for easier navigation.
2026-04-09 move all custom configs stuff to custom.cfg and custom_macros.cfg
    [Line_Purge.cfg, Smart_Park.cfg, advanced_nozzle_cleaner.cfg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]
2026-04-16 dead zones
    [dead-zone-boundary-frame.stl]
2026-04-16 DXC and safe bed mesh range
    [custom.cfg, custom_macros.cfg]
2026-04-18 stop printing
    [custom_macros.cfg]
2026-04-21 configs fix
    [custom.cfg, printer.cfg]
2026-05-03 dead zone door
    [custom.cfg]
